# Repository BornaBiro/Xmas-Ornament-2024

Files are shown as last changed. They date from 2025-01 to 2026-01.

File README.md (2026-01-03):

# Xmas Ornament - 2024 update
New and updated DIY Xmas Ornament based around STM32C011 MCU.

# ! NOTE ! - PLEASE READ THIS FIRST!
Before making this project keep in mind that this PCB has an error. It's not fixed in design files, you will need it to fix it yourself!

Issues is that STM32 MCU is missing it's GND.
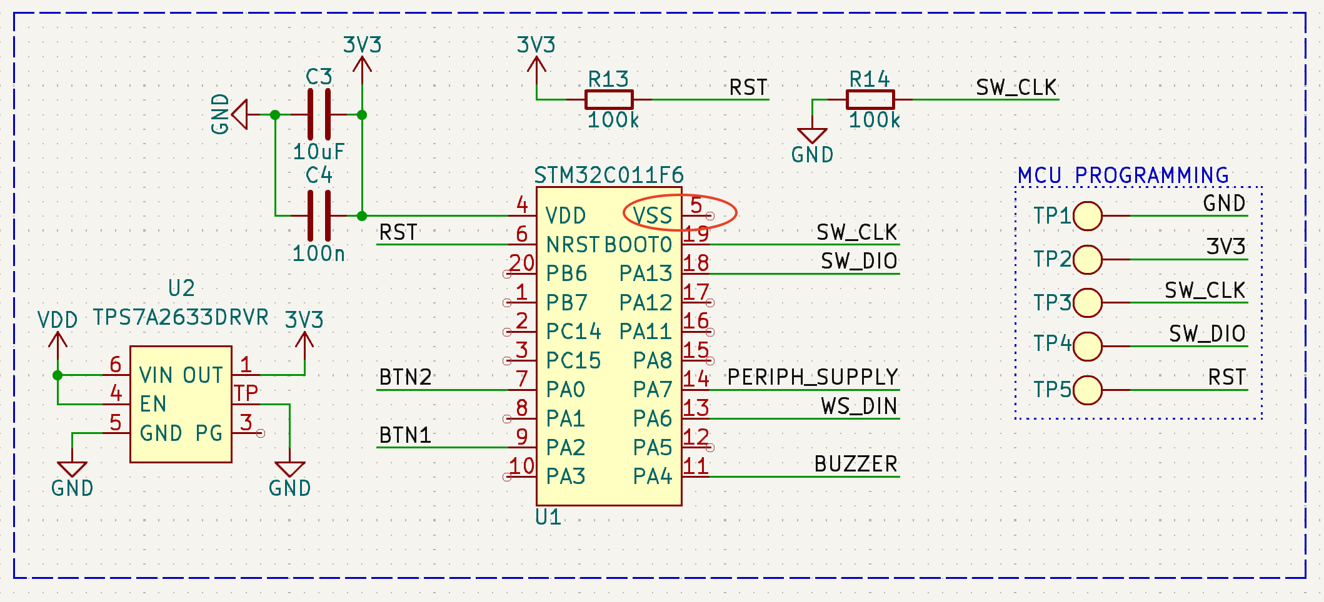
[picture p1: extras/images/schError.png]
PCB Image


The fix is to scratch the soldermask and connect GND of the MCU with a piece of very thin wire.

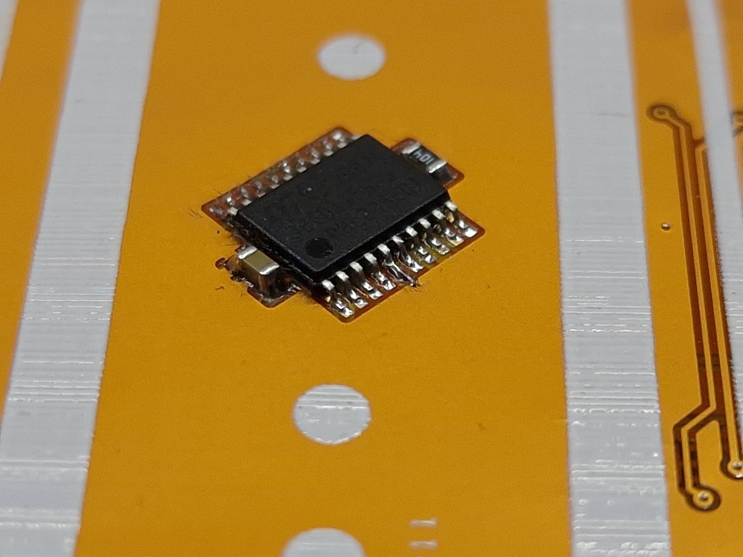
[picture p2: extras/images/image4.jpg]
PCB Image


## Board features
- Low power STM32C011F6PF MCU with 48MHz internal clock
- 12 x WS2812B-2020 RGB Adressable LEDs
- Buzzer for playing simple melodies
- Two push buttons both with wake up capability
- JST battry connector
- Li-Ion battery charger
- Low power compatable - 2uA deep sleep current
- USB-C connector for charging

I made two version of the project: one with the flex PCB (ordered from JLCPCB) and the other one with regular two layer FR4 PCB.

Flex PCB version:
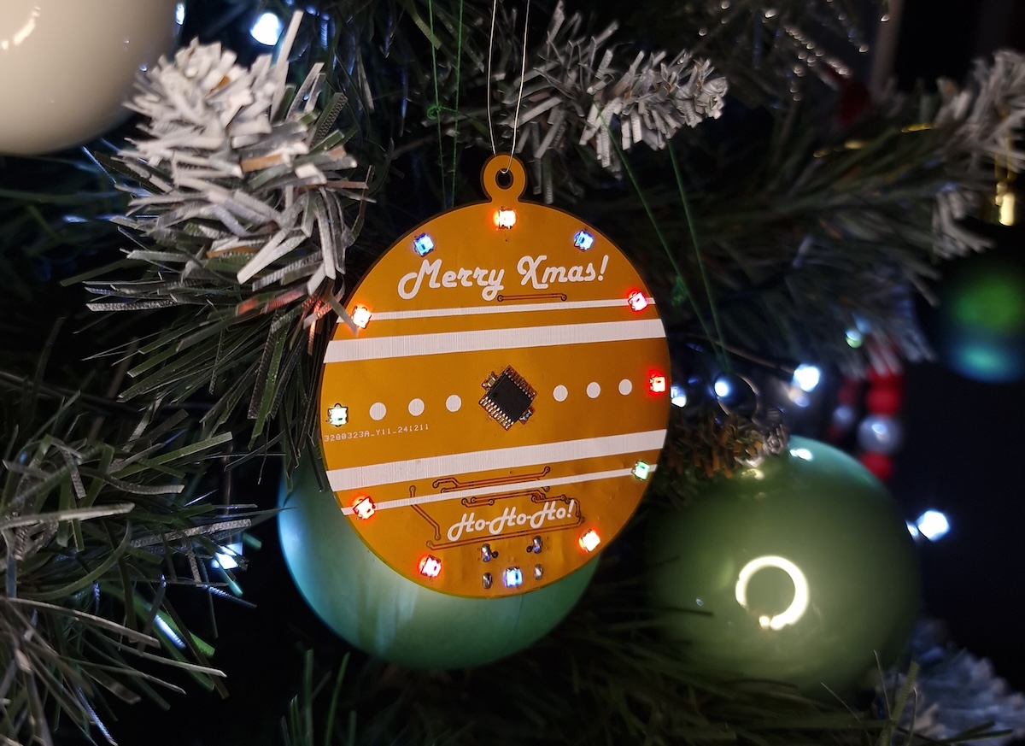
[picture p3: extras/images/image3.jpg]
PCB Image


FR4 PCB version:
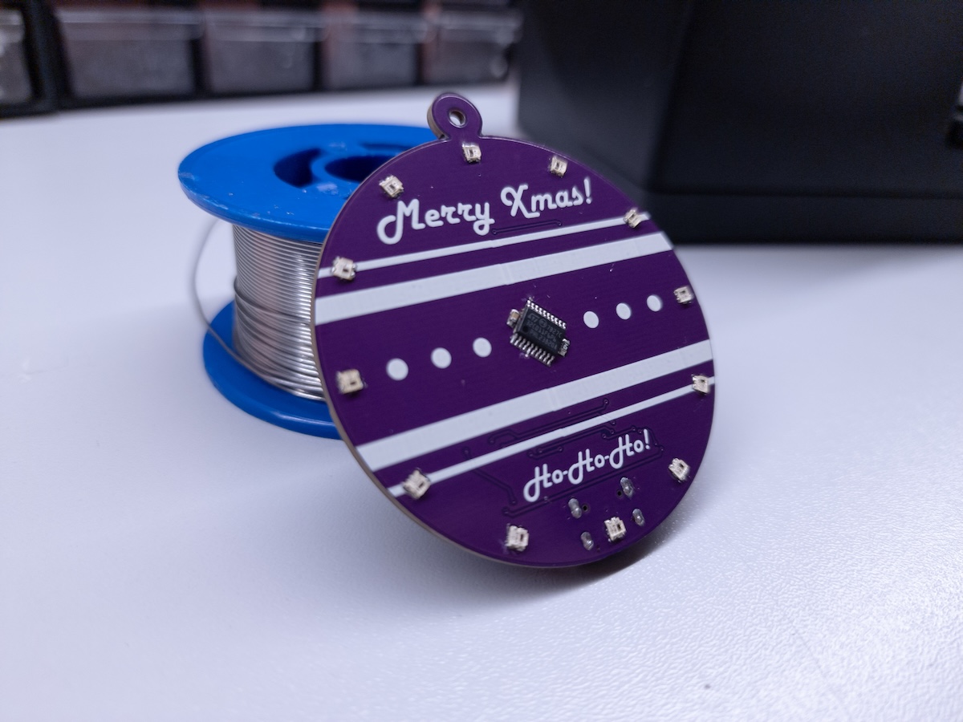
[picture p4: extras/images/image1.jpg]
PCB Image


## Board usage:
There are two buttons for controlling the ornament. At moment of connecting the battery, device is on and it's playing the melodies and also blinking the LEDs. Battery used is Li-Ion 3.7V 601220 100mAh Battery. Please check the polarity of. the battery!

- BTN1:
  - Regular button press:
    - Power on if the device is off
    - Change the melody
  - Multiple press: Noting for now. :)
  - Long press: Power down

- BTN2:
  - Regular button press: Change the LED pattern
  - Multiple press: Noting for now. :)
  - Long press: Mute/Unmute the ornament

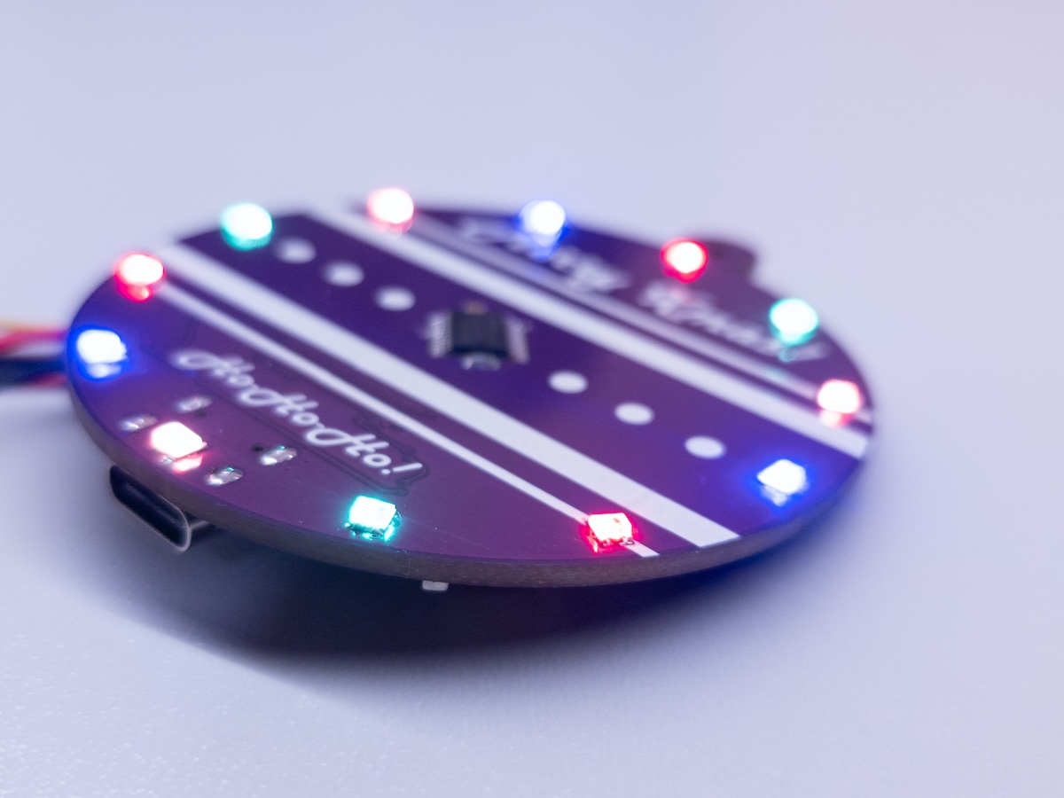
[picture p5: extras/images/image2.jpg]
LEDs


## Requirements
- PC or a laptop
- STM32CubeIDE v1.19.0 or older (yes, older, new v2.0.0 is just bad)
  - I used STM32CubeIDE v1.19.0, Build: 25607_20250703_0907 (UTC)
- STM32C0 FW package v1.4.0
- STLink v2 (ideally with [reset mod](https://chauquest.com/index.php/article/why-your-st-link-v2-reset-doesnt-work-and-how-to-fix-it/))
- Completed PCB
- Jumper cables to connect STLink and PCB
- Soldering iron
- Li-Ion battery
- Electricity for all of that (not optional!)

## Usage
Open the project in STM32CubeIDE, build it (everything should be set-up) by pressing CTRL+B (or CMD+B on Mac) , and run the code. If, on the code run (upload) pop-up window shows up, just press Run button and the code should be uploaded to the board. If not, maybe something ins't soldered correctly, or there is a connection issue with the board or the programmer. To check that, you can use STM32CubeProgrammer - it's faster for testing programmer connection than STM32CubeIDE.

# License
All files written or created by me are using the MIT Licence and can be re-used BUT original author (me) must not be removed!
Part of the code for WS2812 LED Driver (ws2182_hsv() function code) is copied from the [Adafruit_NeoPixel library](https://github.com/adafruit/Adafruit_NeoPixel). Thanks Adafruit!

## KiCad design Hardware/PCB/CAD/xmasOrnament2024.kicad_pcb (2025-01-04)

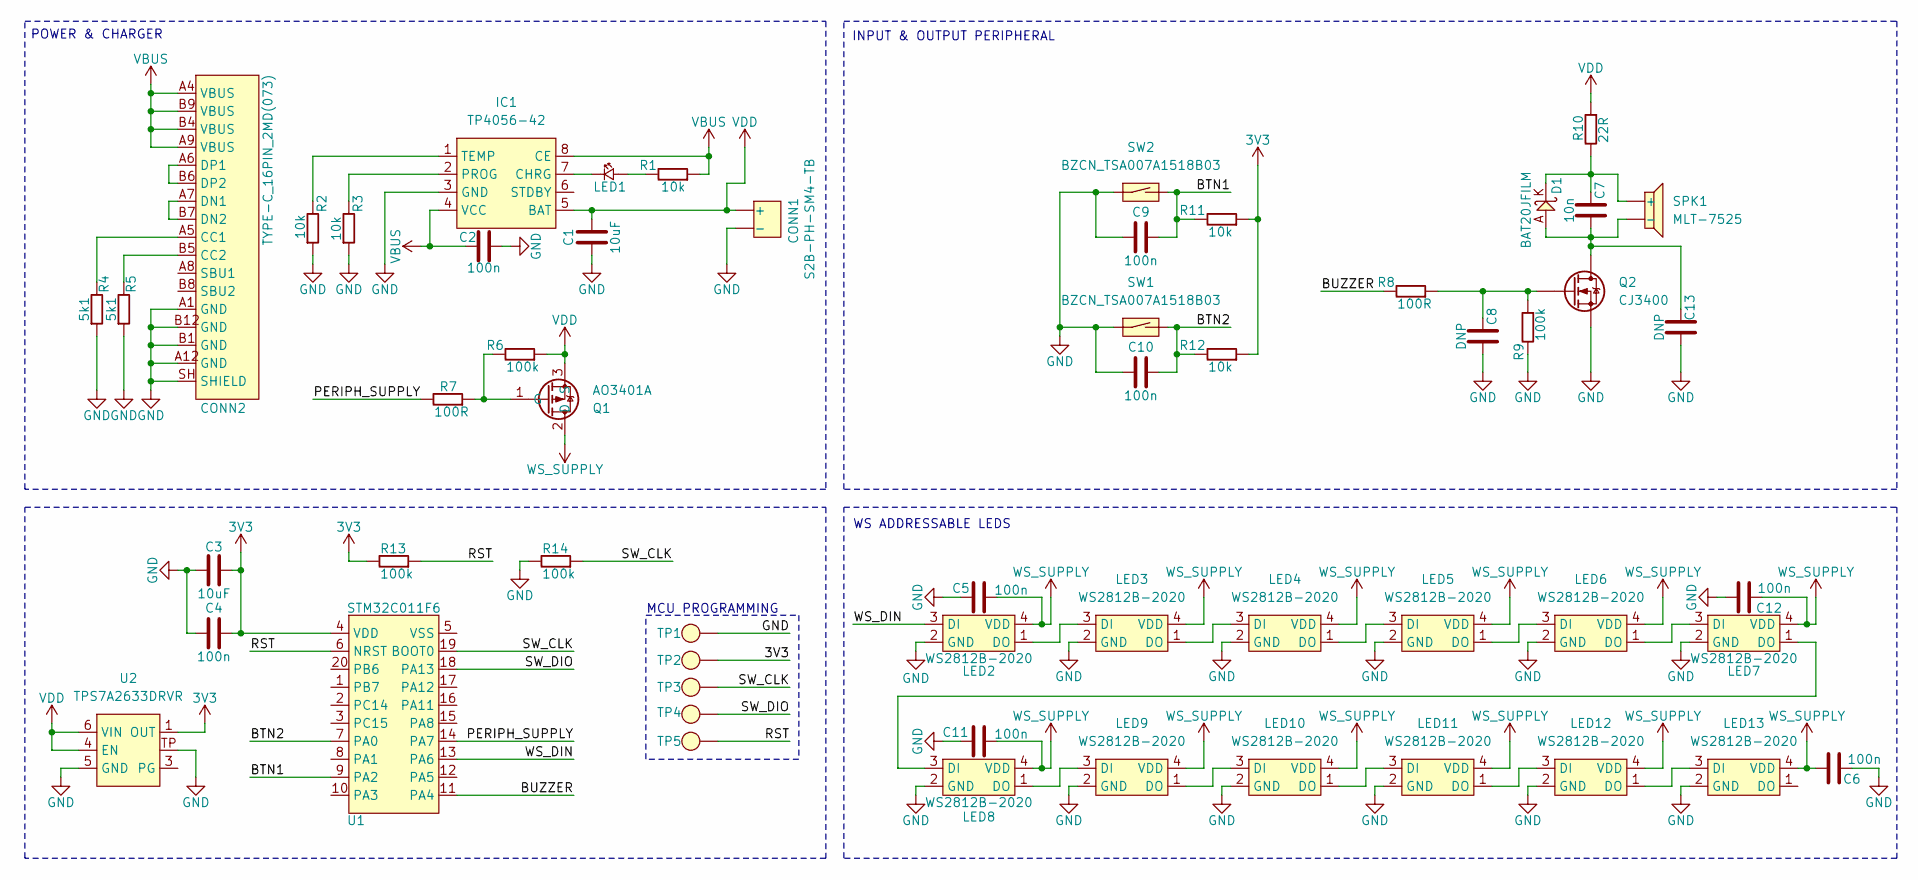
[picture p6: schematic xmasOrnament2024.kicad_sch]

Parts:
C1, C3: 10uF; C1206
C2, C4, C5, C6, C9, C10, C11, C12: 100n; C0603
C7: 10n; C0603
C8, C13: DNP; C0603
CONN1: S2B-PH-SM4-TB; JST_S2B-PH-SM4-TB
CONN2: TYPE-C_16PIN_2MD(073)
D1: BAT20JFILM; SOD323
IC1: TP4056-42; EMSOP
LED1: LED_0603
LED2, LED3, LED4, LED5, LED6, LED7, LED8, LED9, LED10, LED11, LED12, LED13: WS2812B-2020
Q1: AO3401A; SOT-23-3L
Q2: CJ3400; SOT-23-3L
R1, R2, R3, R11, R12: 10k; R0603
R4, R5: 5k1; R0603
R6, R9, R13, R14: 100k; R0603
R7, R8: 100R; R0603
R10: 22R; R0603
SPK1: MLT-7525; MTL-7525
SW1, SW2: BZCN_TSA007A1518B03; TSA007A1518B03
TP1, TP2, TP3, TP4, TP5: TP-1_5mm
U1: STM32C011F6; TSSOP20
U2: TPS7A2633DRVR; WSON-6

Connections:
3V3: C3.2, C4.2, R11.1, R12.1, R13.2, TP2.1 (TP), U1.4 (VDD), U2.1 (OUT)
/BTN1: C9.2, R11.2, SW2.2 (SW2), U1.9 (PA2)
/BTN2: C10.2, R12.2, SW1.2 (SW2), U1.7 (PA0)
/BUZZER: R8.2, U1.11 (PA4)
/PERIPH_SUPPLY: R7.2, U1.14 (PA7)
/RST: R13.1, TP5.1 (TP), U1.6 (NRST)
/SW_CLK: R14.1, TP3.1 (TP), U1.19 (BOOT0)
/SW_DIO: TP4.1 (TP), U1.18 (PA13)
/WS_DIN: LED2.3 (DI), U1.13 (PA6)
GND: C1.1, C2.1, C3.1, C4.1, C5.2, C6.2, C8.1, C9.1, C10.1, C11.2, C12.1, C13.1, CONN1.-, CONN2.A1 (GND), CONN2.A12 (GND), CONN2.B1 (GND), CONN2.B12 (GND), CONN2.SH (SHIELD), IC1.3 (GND), LED2.2 (GND), LED3.2 (GND), LED4.2 (GND), LED5.2 (GND), LED6.2 (GND), LED7.2 (GND), LED8.2 (GND), LED9.2 (GND), LED10.2 (GND), LED11.2 (GND), LED12.2 (GND), LED13.2 (GND), Q2.3 (S), R2.1, R3.1, R4.1, R5.1, R9.2, R14.2, SW1.1 (SW1), SW2.1 (SW1), TP1.1 (TP), U2.5 (GND), U2.TP
unnamed: C7.2, D1.K, R10.2, SPK1.+
unnamed: CONN2.A5 (CC1), R4.2
unnamed: CONN2.B5 (CC2), R5.2
unnamed: CONN2.A7 (DN1), CONN2.B7 (DN2)
unnamed: CONN2.A6 (DP1), CONN2.B6 (DP2)
unnamed: IC1.7 (CHRG), LED1.2 (K)
unnamed: IC1.2 (PROG), R3.2
unnamed: IC1.1 (TEMP), R2.2
unnamed: LED1.1 (A), R1.2
unnamed: LED2.1 (DO), LED3.3 (DI)
unnamed: LED3.1 (DO), LED4.3 (DI)
unnamed: LED4.1 (DO), LED5.3 (DI)
unnamed: LED5.1 (DO), LED6.3 (DI)
unnamed: LED6.1 (DO), LED7.3 (DI)
unnamed: LED7.1 (DO), LED8.3 (DI)
unnamed: LED8.1 (DO), LED9.3 (DI)
unnamed: LED9.1 (DO), LED10.3 (DI)
unnamed: LED10.1 (DO), LED11.3 (DI)
unnamed: LED11.1 (DO), LED12.3 (DI)
unnamed: LED12.1 (DO), LED13.3 (DI)
unnamed: Q1.1 (G), R6.2, R7.1
unnamed: C7.1, C13.2, D1.A, Q2.2 (D), SPK1.-
unnamed: C8.2, Q2.1 (G), R8.1, R9.1
VBUS: C2.2, CONN2.A4 (VBUS), CONN2.A9 (VBUS), CONN2.B4 (VBUS), CONN2.B9 (VBUS), IC1.4 (VCC), IC1.8 (CE), R1.1
VDD: C1.2, CONN1.+, IC1.5 (BAT), Q1.3 (S), R6.1, R10.1, U2.4 (EN), U2.6 (VIN)
WS_SUPPLY: C5.1, C6.1, C11.1, C12.2, LED2.4 (VDD), LED3.4 (VDD), LED4.4 (VDD), LED5.4 (VDD), LED6.4 (VDD), LED7.4 (VDD), LED8.4 (VDD), LED9.4 (VDD), LED10.4 (VDD), LED11.4 (VDD), LED12.4 (VDD), LED13.4 (VDD), Q1.2 (D)

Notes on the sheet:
INPUT & OUTPUT PERIPHERAL
POWER & CHARGER
WS ADDRESSABLE LEDS
MCU PROGRAMMING

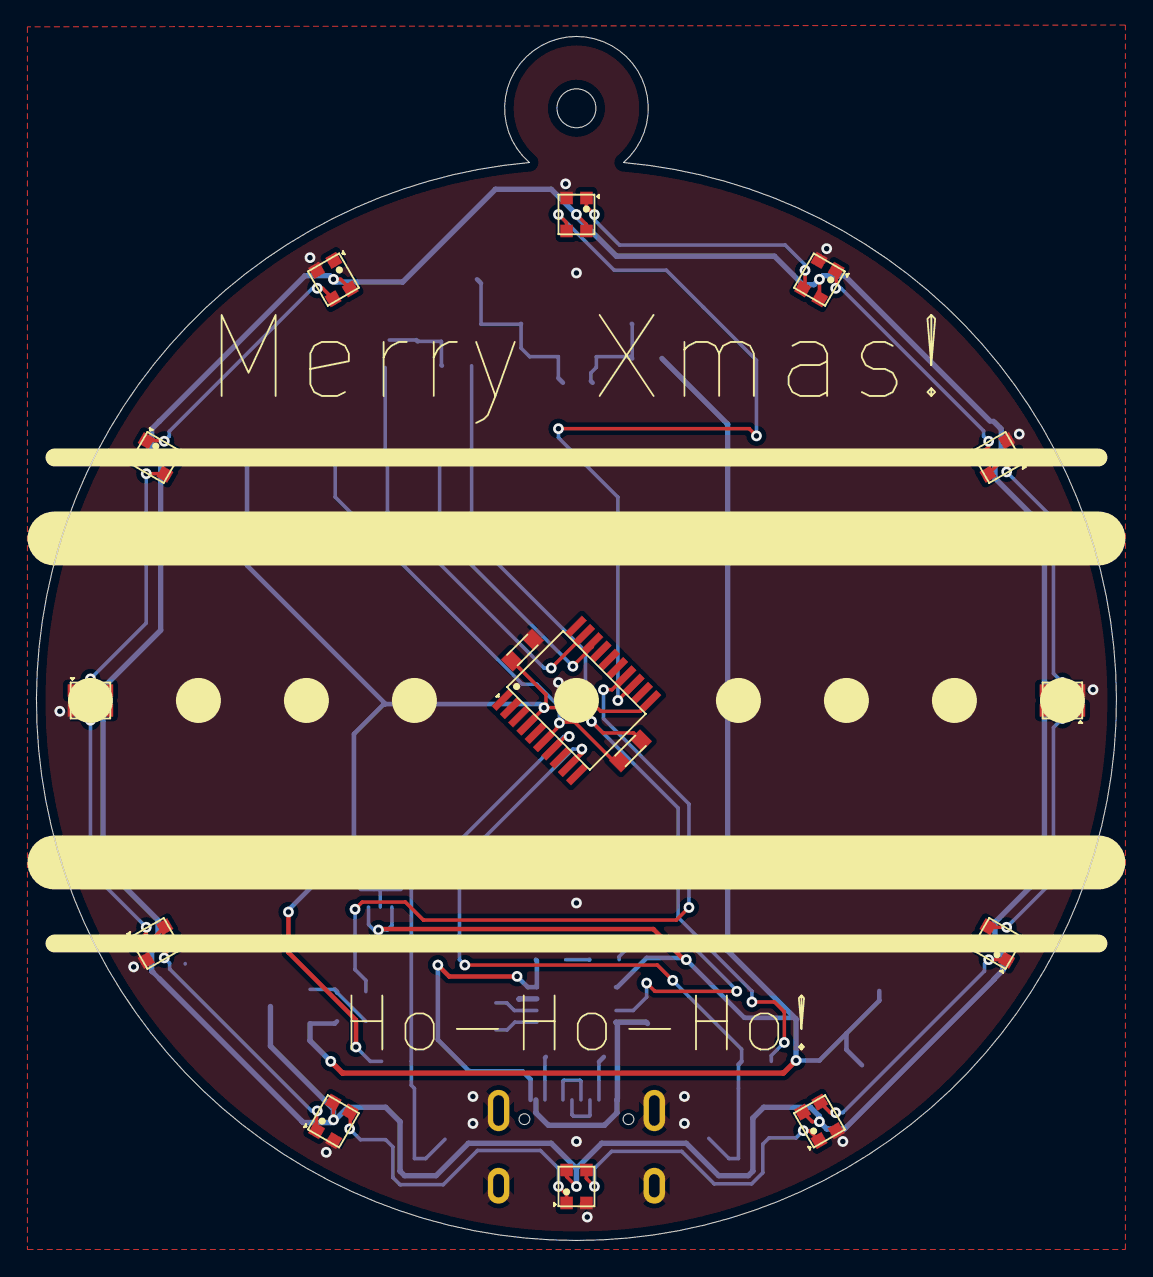
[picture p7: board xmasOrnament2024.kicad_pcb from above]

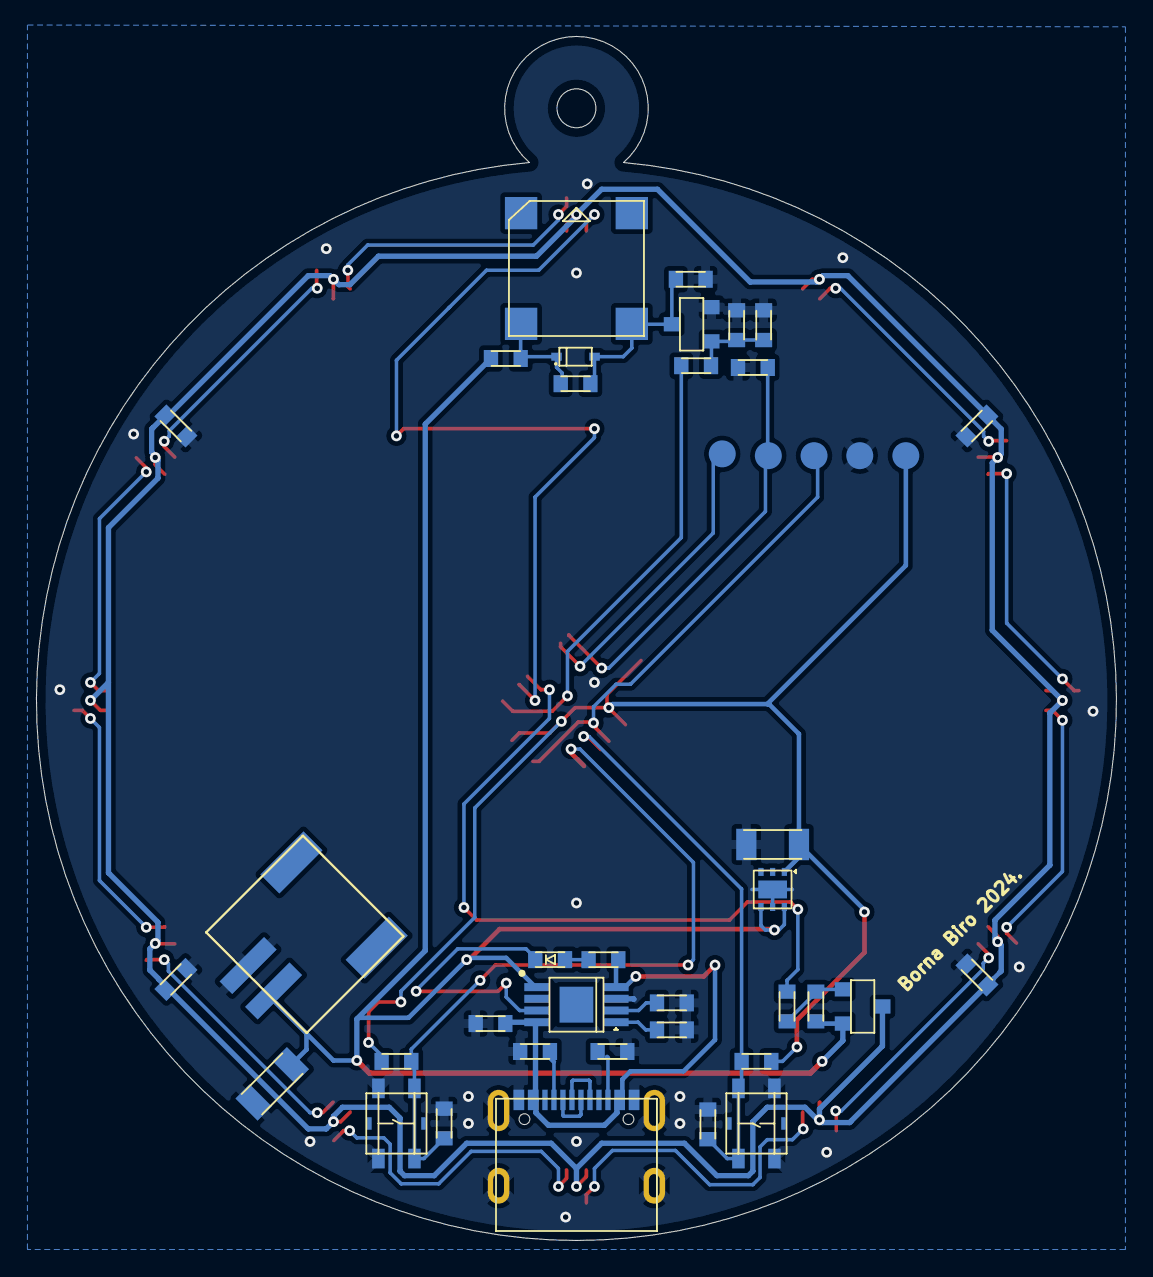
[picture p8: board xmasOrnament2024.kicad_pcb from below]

Board: 2 copper layers, 60.0 x 66.9 mm, 56 parts (41 on the bottom side), 36 nets.

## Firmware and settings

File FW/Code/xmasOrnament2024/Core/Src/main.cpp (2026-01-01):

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
/* Includes ------------------------------------------------------------------*/
#include "main.h"

/* USER CODE BEGIN Includes */
// Include standard C libraries.
#include <stdint.h>
#include <stdbool.h>

// Include the library for the WS LEDs.
#include "WS2812.h"

// Include the library for the buzzer - PWM.
#include "Buzzer.h"

// Include the library for UIwith just one button.
#include "oneButton.h"

// Include the old-school melodies extracted from the xmas light music box.
#include "melodioes.h"

// Include the library for the xmas melody "player".
#include "melodyController.h"

// Include the colors for the LEDs.
#include "colors.h"
/* USER CODE END Includes */

/* USER CODE BEGIN PD */
// Define how long to keep device on. By default, keep it 10 minutes.
#define DEVICE_AUTO_OFF_TIME_MS     (10ULL * 60ULL * 1000ULL)
/* USER CODE END PD */


TIM_HandleTypeDef htim3;
TIM_HandleTypeDef htim14;
DMA_HandleTypeDef hdma_tim3_ch1;

/* USER CODE BEGIN PV */

// Variable that keeps time when the device was turned on, so we know when we need to
// turn it of.
uint32_t onTime = 0;
// Variable used as a "strach-pad" memory for changing the LED pattern.
int ledColorShift = 0;
// Variable used for storing the current mode/pattern of the LEDs.
uint8_t _ledMode = 0;
/* USER CODE END PV */

void SystemClock_Config(void);
static void MX_GPIO_Init(void);
static void MX_DMA_Init(void);
static void MX_TIM3_Init(void);
static void MX_TIM14_Init(void);
/* USER CODE BEGIN PFP */
// Object for both buttons so we can easily create the menu.
OneButton btn1;
OneButton btn2;

// Create an object for the melody controller.
MelodyController melody;

// Helper function that prepares the device for shutdown and shuts down the MCU.
void deviceShutDown();
/* USER CODE END PFP */

/**
  * @brief  The application entry point.
  * @retval int
  */
int main(void)
{

  /* MCU Configuration--------------------------------------------------------*/

  /* Reset of all peripherals, Initializes the Flash interface and the Systick. */
  HAL_Init();

  /* Configure the system clock */
  SystemClock_Config();

  /* Initialize all configured peripherals */
  MX_GPIO_Init();
  MX_DMA_Init();
  MX_TIM3_Init();
  MX_TIM14_Init();
  /* USER CODE BEGIN 2 */

  // Enable the supply for the buzzer and LEDs.
  HAL_GPIO_WritePin(PERIPH_EN_GPIO_Port, PERIPH_EN_Pin, GPIO_PIN_RESET);
  // Wait a little bit.
  HAL_Delay(100ULL);

  // Initialize the buzzer library.
  buzzer_begin(&htim14);

  // Initialize the WS LED library.
  if (!ws2812_begin(&htim3, &hdma_tim3_ch1, TIM_CHANNEL_1, 12, 2, 9, 6, 3))
  {
      while(1);
  }

  // Initialize library for the melody controller - player.
  melody.begin((uint16_t**)currentMelodyNotes, (uint16_t**)currentMelodyDurations, (uint8_t*)melodyElements, sizeof(melodyElements) / sizeof(melodyElements[0]));
  // Start playing the melodies right-away!
  melody.play();
  /* USER CODE END 2 */

  /* Infinite loop */
  /* USER CODE BEGIN WHILE */
  while (1)
  {
      // Check the button(s).
      btn1.loop();
      btn2.loop();

      // Update the music controller. Return what is happening to the melodies.
      // 0 - no change, 1 - note has changed, 2 - melody has changed.
      int update = melody.update();

      // If the BTN1 is pressed - change the melody.
      if (btn1.isPressed())
              melody.next();

      // If the BTN2 is pressed - change the LED mode/pattern.
      if (btn2.isPressed())
      {
          _ledMode = (_ledMode + 1) % 3;
      }

      // If the BTN2 is long pressed - toggle the mute for the melody.
      // The melody is still being played in the background.
      if (btn2.isLongPressed())
      {
          melody.setMute(!melody.getMute());
      }

      // If the BTN1 is long pressed - the same one for the power up,
      // shut down the device.
      if (btn1.isLongPressed())
      {
          deviceShutDown();
      }

      // Update the LEDs only if the melody or note is changed.
      if (update)
      {
          // If the melody is changed - change the led pattern. Only three patterns
          // are available for now.
          if (update == 2)
              _ledMode = (_ledMode + 1) % 3;

          // If the first mode is selected - toggle between red-yellow and blue-green LEDs,
          // but also, shuffle them so the color are not on the same position.
          if (_ledMode == 0)
          {
              // LUT for easier access and change of the color.
              // 0 = Red, 2 = Yellow, But also, 1 = Green, 3 = Blue. So, with this LUT, we can
              // very easily select the color of the LED.
              uint8_t colors[] = {0, 2};

              // Set the new colors on LEDs.
              for (int i = 0; i < 12; i++)
              {
                  uint8_t _currentColorIndex = colors[(i + ledColorShift / 2) % 2] + (ledColorShift & 1);
                  ws2812_setPixelColor(i, ws2812_hsv(xmasColors[_currentColorIndex].hue, xmasColors[_currentColorIndex].sat, xmasColors[_currentColorIndex].val));
              }

              // Update the LED pattern variable.
              ledColorShift++;

              // Push the new colors to the LEDs.
              ws2812_show();
          }
          // This modes just shuffles the colors around on the LEDs in circle.
          // The colors are old-school colors: Yellow, Green, Red, Blue, Pink.
          else if (_ledMode == 1)
          {
              // Set the new colors on LEDs.
              for (int i = 0; i < 12; i++)
              {
                  ws2812_setPixelColor(i, ws2812_hsv(xmasColors[(ledColorShift + i) % 5].hue, xmasColors[(ledColorShift + i) % 5].sat, xmasColors[(ledColorShift + i) % 5].val));
              }

              // Update the LED pattern variable.
              ledColorShift++;

              // Push the new colors to the LEDs.
              ws2812_show();
          }
          // This modes just shows all these colors on all LEDs and changes them on every note change.
          else if (_ledMode == 2)
          {
              // Set the new colors on LEDs.
              for (int i = 0; i < 12; i++)
              {
                  ws2812_setPixelColor(i, ws2812_hsv(xmasColors[ledColorShift % 5].hue, xmasColors[ledColorShift % 5].sat, xmasColors[ledColorShift % 5].val));
              }
              ledColorShift++;

              // Push the new colors to the LEDs.
              ws2812_show();
          }
      }

      // If 10 minutes passed, shut down the ornament and prepare everything for the power up on the button.
      if ((uint32_t)(HAL_GetTick() - onTime) > DEVICE_AUTO_OFF_TIME_MS)
      {
          // Update the timer.
          onTime = HAL_GetTick();

          // Go to the shut-down routine.
          deviceShutDown();
      }
    /* USER CODE END WHILE */

    /* USER CODE BEGIN 3 */
  }
  /* USER CODE END 3 */
}

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
/* USER CODE BEGIN 4 */
void HAL_GPIO_EXTI_Rising_Callback(uint16_t GPIO_Pin)
{
    // Send the timestamps of the buttons into the OneButton library at rising edge.
    if (GPIO_Pin == GPIO_PIN_2) btn1.updateState(HAL_GetTick(), 1);
    if (GPIO_Pin == GPIO_PIN_0) btn2.updateState(HAL_GetTick(), 1);
}

void HAL_GPIO_EXTI_Falling_Callback(uint16_t GPIO_Pin)
{
    // Send the timestamps of the buttons into the OneButton library at falling edge.
    if (GPIO_Pin == GPIO_PIN_2) btn1.updateState(HAL_GetTick(), 0);
    if (GPIO_Pin == GPIO_PIN_0) btn2.updateState(HAL_GetTick(), 0);
}

void deviceShutDown()
{
    // Turn off all LEDs.
    for (int i = 0; i < 12; i++)
    {
        ws2812_setPixelColor(i, 0);
    }

    // Push the new colors to the LEDs.
    ws2812_show();

    // Disable the supply to the LEDs and buzzer.
    HAL_GPIO_WritePin(PERIPH_EN_GPIO_Port, PERIPH_EN_Pin, GPIO_PIN_SET);

    // Disable the timers for LEDs and buzzer.
    HAL_TIM_PWM_DeInit(&htim14);
    HAL_TIM_PWM_DeInit(&htim3);

    while(HAL_GPIO_ReadPin(GPIOA, GPIO_PIN_2) == GPIO_PIN_RESET);

    // Set the wake up pins.
    //HAL_PWR_DisableWakeUpPin(PWR_WAKEUP_PIN1);
    HAL_PWR_DisableWakeUpPin(PWR_WAKEUP_PIN4);
    //HAL_PWR_EnableWakeUpPin(PWR_WAKEUP_PIN1_LOW);
    HAL_PWR_EnableWakeUpPin(PWR_WAKEUP_PIN4_LOW);
    __HAL_PWR_CLEAR_FLAG(PWR_FLAG_WUF);

    // Disable the tick
    HAL_SuspendTick();

    // Shut-down whole device.
    HAL_PWREx_EnterSHUTDOWNMode();
}
/* USER CODE END 4 */
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


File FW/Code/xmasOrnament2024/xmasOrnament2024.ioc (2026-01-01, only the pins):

Mcu.UserName=STM32C011F6Px
PA0.GPIO_Label=USER_BTN2
PA0.Signal=GPXTI0
PA2.GPIO_Label=USER_BTN1
PA2.Signal=GPXTI2
PA4.Signal=S_TIM14_CH1
PA6.Signal=S_TIM3_CH1
PA7.GPIO_Label=PERIPH_EN
PA7.Signal=GPIO_Output

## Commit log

2024-12-03 PCB added (still not finished).
    [xmasOrnament2024.kicad_pcb, xmasOrnament2024.kicad_sch]
2024-12-04 Board finished.
    [xmasOrnament2024.kicad_pcb, xmasOrnament2024.kicad_sch]
2024-12-07 Added VREG.
    [xmasOrnament2024.kicad_pcb, xmasOrnament2024.kicad_sch]
2024-12-10 Added gerber files.
    [xmasOrnament2024-B_Cu.gbl, xmasOrnament2024-B_Mask.gbs, xmasOrnament2024-B_Paste.gbp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]
2025-01-04 Sync - Changed typo on PCB.
    [xmasOrnament2024-B_Cu.gbl, xmasOrnament2024-B_Mask.gbs, xmasOrnament2024-B_Paste.gbp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]
2026-01-02 Updated buzzer component values.
    [xmasOrnament2024.kicad_sch]

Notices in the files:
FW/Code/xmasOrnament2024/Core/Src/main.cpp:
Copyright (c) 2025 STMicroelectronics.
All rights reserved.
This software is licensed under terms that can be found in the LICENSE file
